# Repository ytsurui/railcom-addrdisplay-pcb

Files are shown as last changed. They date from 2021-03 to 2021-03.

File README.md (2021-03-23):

# Railcom (BiDi) Display Unit PCB Data

NMRA DCCの双方向通信規格 (BiDi, Railcom) に準拠した通信信号を受信し、DCC車両のアドレスを表示する機器の基板設計データです。 \
マイコンが取り外せ、基板上に通信信号を横取りできる端子が設けてあるため、Railcom対応機器の開発ベースとしても利用できます。

本リポジトリには、回路図、基板設計データを含みます。

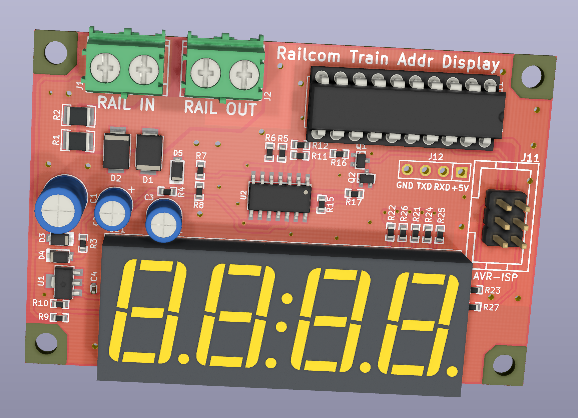
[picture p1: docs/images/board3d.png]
PCB 3D Preview


### 主要スペック

  * Railcom Display Unitを介して接続した線路上で動作している、Railcom対応デコーダの車両アドレスを7セグLEDに表示
  * Railcom Channel1 app:adr_low / app_adr_highの受信に対応 \
    (それ以外のRailcomパケットは無視します)

### 動作確認した環境
#### コマンドステーション
  * Roco Z21

#### デコーダー
  * Lenz SILVER+ Mini

### 閲覧・編集に必要なCAD (開発環境)
  * KiCad Version (5.1.9)-1 (またはそれ以降)

### 対応するファームウェア
  * [Railcom Train Address Display Unit Firmware for ATtiny2313](https://github.com/ytsurui/railcom-addrdisplay-firmware)

### 各種ドキュメント
  * [パーツリスト](docs/partslist.md)

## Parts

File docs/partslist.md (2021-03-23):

# Parts List (Railcom Display Unit)

<table>
  <th>
    <td>Name</td>
    <td>Package</td>
    <td>Count</td>
    <td>Shop Links</td>
  </th>
  <tr>
    <td>U1</td>
    <td>78L05</td>
    <td>SOT-89-3</td>
    <td>1</td>
    <td></td>
  </tr>
  <tr>
    <td>U2</td>
    <td>LM339<br>(Quad Comparator)</td>
    <td>SOIC-14</td>
    <td>1</td>
    <td></td>
  </tr>
  <tr>
    <td>U11</td>
    <td>ATtiny2313<br>ATtiny2313A<br>ATtiny4313</td>
    <td>PDIP-20</td>
    <td>1</td>
    <td><a href="https://akizukidenshi.com/catalog/g/gI-01600/">秋月電子通商</a></td>
  </tr>
  <tr>
    <td>D1, D2</td>
    <td>SR54F<br>(Schottky Diode, 5A)</td>
    <td>SMBF</td>
    <td>2</td>
    <td><a href="https://akizukidenshi.com/catalog/g/gI-06125/">秋月電子通商</a></td>
  </tr>
  <tr>
    <td>D3, D4, D5</td>
    <td>GS1010FL<br>(Diode, 1A)</td>
    <td>SOD-123FL</td>
    <td>3</td>
    <td><a href="https://akizukidenshi.com/catalog/g/gI-06014/">秋月電子通商</a></td>
  </tr>
  <tr>
    <td>D11</td>
    <td>OSL40652<br>4-Digit 7-Segment LED Display (Common Anode Type)</td>
    <td>-</td>
    <td>1</td>
    <td></td>
  </tr>
  <tr>
    <td>Q1, Q2</td>
    <td>SSM3K7002BFU<br>SSM3K7002CFU<br>SSM3K7002KFU<br>(N-ch Single MOSFET)</td>
    <td>SC-70<br>SOT-323</td>
    <td>2</td>
    <td><a href="https://akizukidenshi.com/catalog/g/gI-08576/">秋月電子通商</a></td>
  </tr>
  <tr>
    <td>C1</td>
    <td>25PK220MEFC6.3X11<br>(220uF Capacitor)</td>
    <td></td>
    <td>1</td>
    <td><a href="https://www.digikey.jp/product-detail/ja/rubycon/25PK220MEFC6.3X11/1189-3986-ND/3563070">Digikey (ja)</a><br><a href="https://akizukidenshi.com/catalog/g/gP-03180/">秋月電子通商</a></td>
  </tr>
  <tr>
    <td>C2, C3</td>
    <td>25PK100MEFC5X11<br>(100uF Capacitor)</td>
    <td>-</td>
    <td>2</td>
    <td><a href="https://akizukidenshi.com/catalog/g/gP-03122/">秋月電子通商</a></td>
  </tr>
  <tr>
    <td>C4, C11</td>
    <td><br>(0.1uF 25V 1005)</td>
    <td>1.0x0.5mm (1005)</td>
    <td>2</td>
    <td><a href="https://www.digikey.jp/product-detail/ja/murata-electronics/GRM155R71H104KE14J/490-13342-1-ND/5973352">Digikey (ja)</a><br />
    <a href="https://www.digikey.jp/product-detail/en/murata-electronics/GRM155R71H104KE14J/490-13342-1-ND/5973352">Digikey (en)</a><br />
    <a href="https://akizukidenshi.com/catalog/g/gP-13377/">秋月電子通商</a></td>
  </tr>
  <tr>
    <td>R1, R2</td>
    <td>ERJ-14YJ3R6U<br>(3.6ohm 1/2W 3225)</td>
    <td>3.2x2.5mm (3225)</td>
    <td>2</td>
    <td><a href="https://www.digikey.jp/product-detail/ja/panasonic-electronic-components/ERJ-14YJ3R6U/P3.6VCT-ND/282552">Digikey (ja)</a></td>
  </tr>
  <tr>
    <td>R3, R4</td>
    <td>(220ohm 1/10W 1608)</td>
    <td>1.6x0.8mm (1608)</td>
    <td>2</td>
    <td></td>
  </tr>
  <tr>
    <td>R5</td>
    <td>MCR03ERTJ274<br>(270kohm 1/10W 1608)</td>
    <td>1.6x0.8mm (1608)</td>
    <td>1</td>
    <td><a href="https://www.digikey.jp/product-detail/ja/rohm-semiconductor/MCR03ERTJ274/RHM270KCGCT-ND/4084390">Digikey (ja)</a></td>
  </tr>
  <tr>
    <td>R6, R15, R21-R27</td>
    <td>1kohm 1/10W 1608</td>
    <td>1.6x0.8mm (1608)</td>
    <td>9</td>
    <td><a href="https://www.digikey.jp/products/ja/resistors/chip-resistor-surface-mount/52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">Digikey (ja)</a><br>
    <a href="https://www.digikey.jp/products/en/resistors/chip-resistor-surface-mount/52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">Digikey (en)</a><br>
    <a href="https://akizukidenshi.com/catalog/g/gR-14122/">秋月電子通商</a></td>
  </tr>
  <tr>
    <td>R7</td>
    <td>820ohm 1/10W 1608</td>
    <td>1.6x0.8mm (1608)</td>
    <td>1</td>
    <td></td>
  </tr>
  <tr>
    <td>R8</td>
    <td>33kohm 1/10W 1608</td>
    <td>1.6x0.8mm (1608)</td>
    <td>1</td>
    <td></td>
  </td>
  <tr>
    <td>R9-R12</td>
    <td>10kohm 1/10W 1608</td>
    <td>1.6x0.8mm (1608)</td>
    <td>4</td>
    <td><a href="https://www.digikey.jp/products/ja/resistors/chip-resistor-surface-mount/52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">Digikey (ja)</a><br>
    <a href="https://www.digikey.jp/products/en/resistors/chip-resistor-surface-mount/52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">Digikey (en)</a><br>
    <a href="https://akizukidenshi.com/catalog/g/gR-06103/">秋月電子通商</a></td>
  </tr>
  <tr>
    <td>R16, R17</td>
    <td>330ohm 1/10W 1608</td>
    <td>1.6x0.8mm (1608)</td>
    <td>2</td>
    <td><a href="https://www.digikey.jp/products/ja/resistors/chip-resistor-surface-mount/52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">Digikey (ja)</a><br>
    <a href="https://www.digikey.jp/products/en/resistors/chip-resistor-surface-mount/52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">Digikey (en)</a><br>
    <a href="https://akizukidenshi.com/catalog/g/gR-06331/">秋月電子通商</a></td>
  </tr>
  <tr>
    <td>J1, J2</td>
    <td>Connector</td>
    <td>-</td>
    <td>2</td>
    <td><a href="https://akizukidenshi.com/catalog/g/gP-01306/">秋月電子通商</a></td>
  </tr>
</table>

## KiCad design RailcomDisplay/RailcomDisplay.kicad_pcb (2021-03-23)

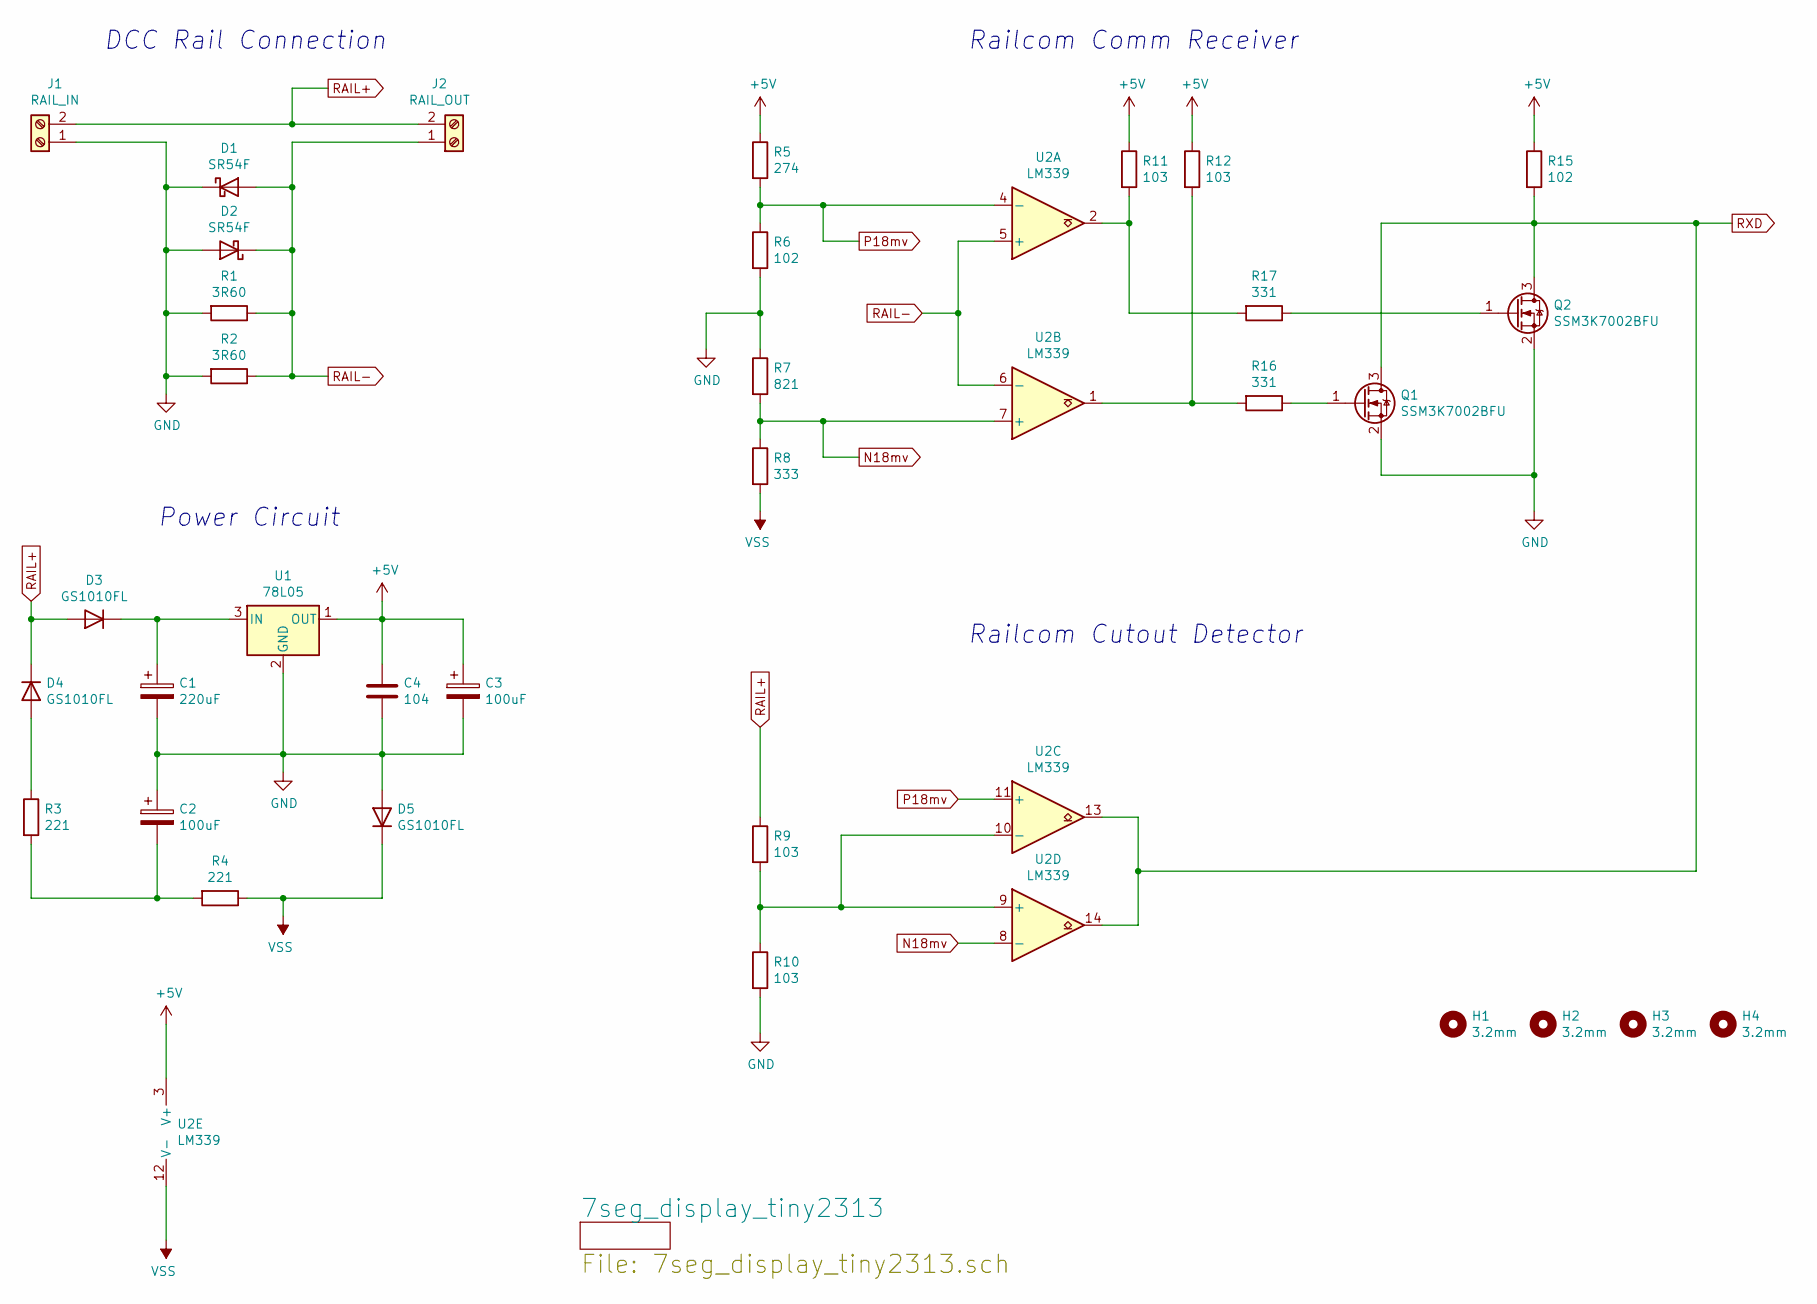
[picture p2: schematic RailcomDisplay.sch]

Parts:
C1: 220uF; CAP_TH_6.3x11
C2, C3: 100uF; CAP_TH_5x11
C4: 104; C_1005
D1, D2: SR54F; SMBF
D3, D4, D5: GS1010FL; SOD-123FL
H1, H2, H3, H4: 3.2mm; HOLE_3.2mm
J1: RAIL_IN; TB111-2
J2: RAIL_OUT; TB111-2
Q1, Q2: SSM3K7002BFU; SC-70
R1, R2: 3R60; R_3225
R3, R4: 221; R_1608
R5: 274; R_1608
R6, R15: 102; R_1608
R7: 821; R_1608
R8: 333; R_1608
R9, R10, R11, R12: 103; R_1608
R16, R17: 331; R_1608
U1: 78L05; SOT-89-3
U2: LM339; SOIC-14

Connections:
+5V: C3.1, C4.1, R5.1, R11.1, R12.1, R15.1, U1.1 (OUT), U2.3 (V+); also elsewhere on the board
GND: C1.2, C2.1, C3.2, C4.2, D1.1 (K), D2.2 (A), D5.2 (A), J1.1, Q1.2 (S), Q2.2 (S), R1.2, R2.2, R6.2, R7.1, R10.2, U1.2 (GND); also elsewhere on the board
N18mv: R7.2, R8.1, U2.7 (+), U2.8 (-)
unnamed: C1.1, D3.1 (K), U1.3 (IN)
unnamed: C2.2, R3.2, R4.2
unnamed: D4.2 (A), R3.1
unnamed: Q1.1 (G), R16.1
unnamed: Q2.1 (G), R17.1
unnamed: R9.2, R10.1, U2.9 (+), U2.10 (-)
unnamed: R11.2, R17.2, U2.2
unnamed: R12.2, R16.2, U2.1
P18mv: R5.2, R6.1, U2.4 (-), U2.11 (+)
RAIL+: D3.2 (A), D4.1 (K), J1.2, J2.2, R9.1
RAIL-: D1.2 (A), D2.1 (K), J2.1, R1.1, R2.1, U2.5 (+), U2.6 (-)
RXD: Q1.3 (D), Q2.3 (D), R15.2, U2.13, U2.14; also elsewhere on the board
VSS: D5.1 (K), R4.1, R8.2, U2.12 (V-)

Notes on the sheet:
Railcom Cutout Detector
Power Circuit
DCC Rail Connection
Railcom Comm Receiver

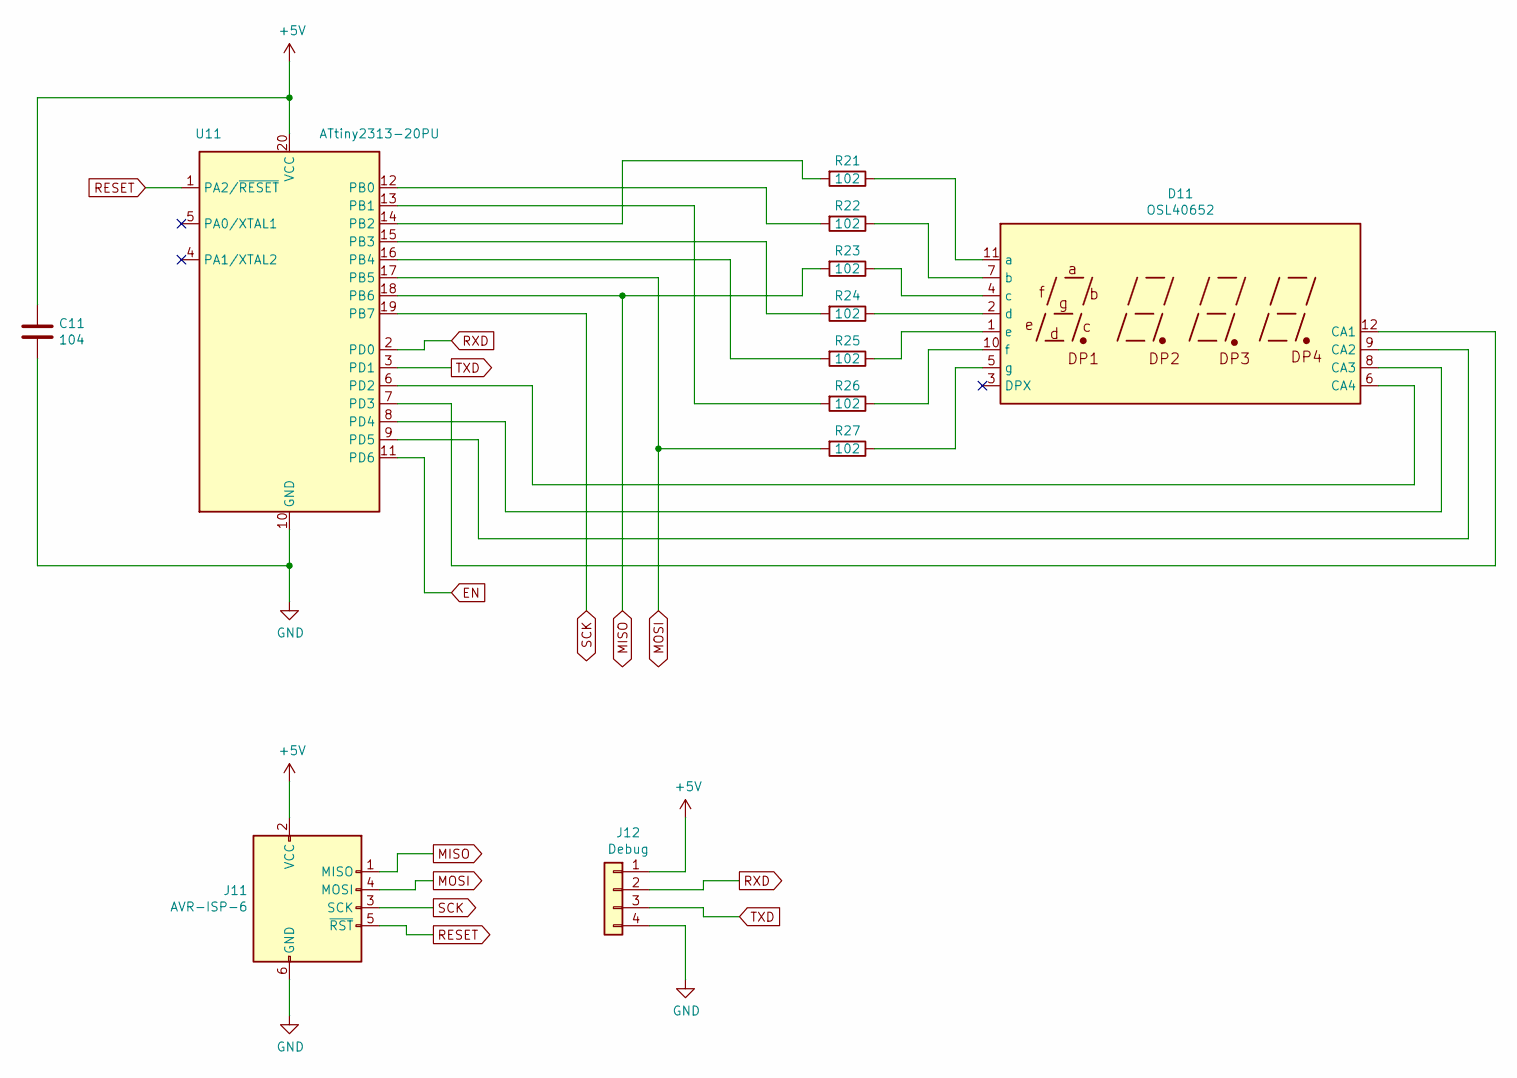
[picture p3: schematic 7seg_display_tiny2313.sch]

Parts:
C11: 104; C_1005
D11: OSL40652; OSL40562
J11: AVR-ISP-6; pin_array_3x2_Block
J12: Debug; pin_array_1x4
R21, R22, R23, R24, R25, R26, R27: 102; R_1608
U11: ATtiny2313-20PU; PDIP20

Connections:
+5V: C11.1, J11.2 (VCC), J12.1, U11.20 (VCC); also elsewhere on the board
EN: U11.11 (PD6)
GND: C11.2, J11.6 (GND), J12.4, U11.10 (GND); also elsewhere on the board
MISO: J11.1 (MISO), R23.2, U11.18 (PB6)
MOSI: J11.4 (MOSI), R27.2, U11.17 (PB5)
unnamed: D11.1 (e), R25.1
unnamed: D11.2 (d), R24.1
unnamed: D11.4 (c), R23.1
unnamed: D11.5 (g), R27.1
unnamed: D11.6 (CA4), U11.6 (PD2)
unnamed: D11.7 (b), R22.1
unnamed: D11.8 (CA3), U11.8 (PD4)
unnamed: D11.9 (CA2), U11.9 (PD5)
unnamed: D11.10 (f), R26.1
unnamed: D11.11 (a), R21.1
unnamed: D11.12 (CA1), U11.7 (PD3)
unnamed: R21.2, U11.14 (PB2)
unnamed: R22.2, U11.12 (PB0)
unnamed: R24.2, U11.15 (PB3)
unnamed: R25.2, U11.16 (PB4)
unnamed: R26.2, U11.13 (PB1)
RESET: J11.5 (~RST), U11.1 (PA2/~RESET)
RXD: J12.2, U11.2 (PD0); also elsewhere on the board
SCK: J11.3 (SCK), U11.19 (PB7)
TXD: J12.3, U11.3 (PD1)

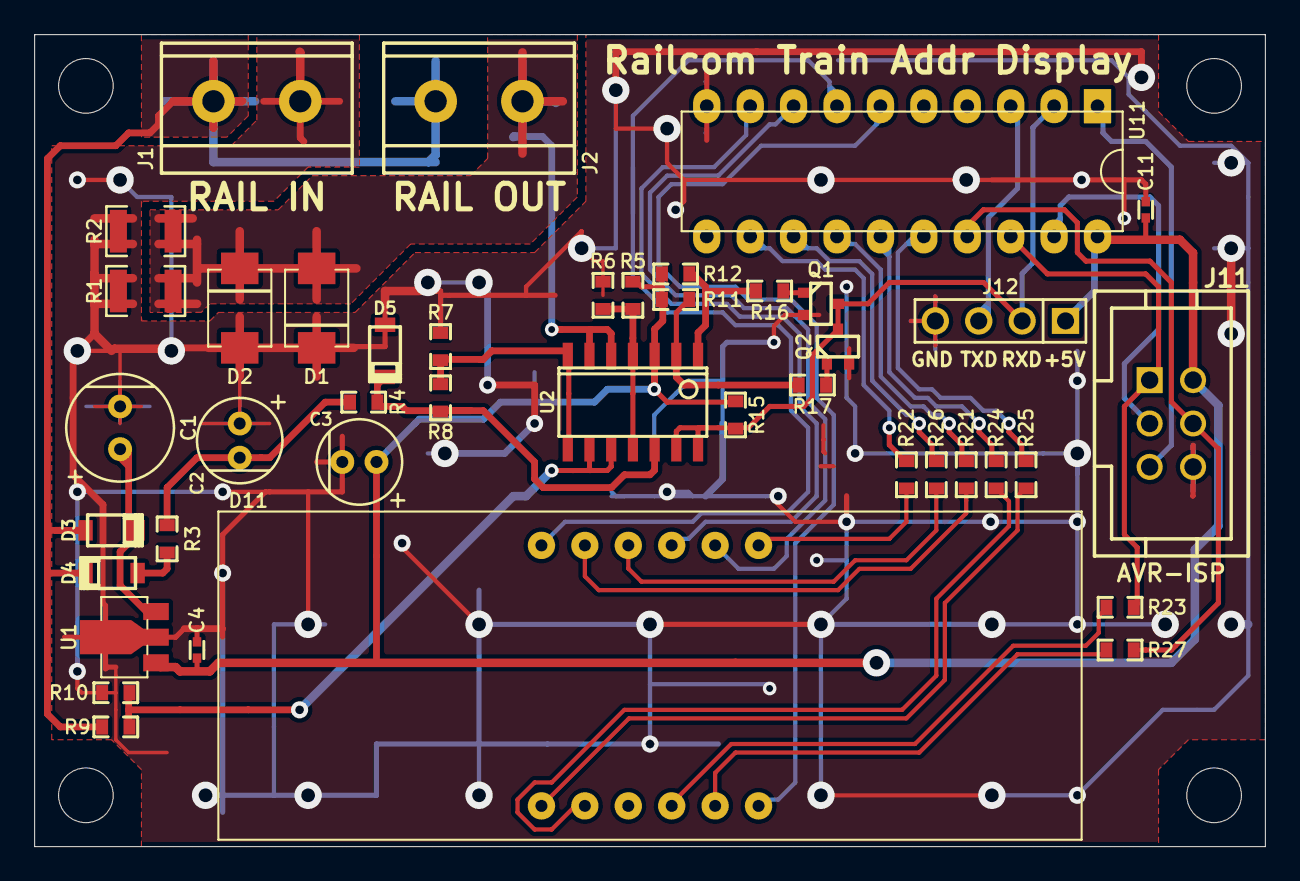
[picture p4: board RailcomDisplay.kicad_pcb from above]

Board: 2 copper layers, 72.0 x 47.5 mm, 46 parts (0 on the bottom side), 37 nets.
